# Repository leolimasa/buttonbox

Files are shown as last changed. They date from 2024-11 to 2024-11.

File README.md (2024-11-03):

# buttonbox

A circuit board for Arduino nano with HID buttons for flight simulators.

2x3 rotary encoders in a circuit board.

## Features

* Heading (heading hold)
* Altitude (FLC)
* Vertical speed (VS)
* Speed (IAS hold)
* Altimeter
* COM radio

## Future

The goal is to have a 2x4 rotary encoders board with an extra 8 buttons. 

The amount of switches is limited by the number of pins on the Arduino nano. An alternative to increase that without using a multiplexer is to wire the switches in a matrix.

Each rotary takes 3 buttons. With 8 rotaries, that's 24 buttons.

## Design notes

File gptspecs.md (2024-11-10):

Below are specifications for a program that reads from an arduino serial device and prints the messages to the console. Write the program in Rust, and ensure that each message type has its own separate struct with the appropriate fields, there is a function to parse the raw bytes into the appropriate struct, and a function to print the struct to the console.

Specification:

# Serial protocol

* Each message is a collection of parameters
* A message starts with the STX (start of text) byte
* The message ends with the ETX (end of text) byte
* Parameters are delimited by the US (unit separator) byte

## Message types

Messages are identified by the first parameter. The first parameter is always a single byte that identifies the message type. 

The following message types are supported:

### Rotary change

Message type: `R`

Parameters:

* index, 4 byte int: The index of the rotary encoder that changed
* direction, 1 byte int: The direction of the change. 1 for clockwise, 0 for counter-clockwise

### Rotary click

Message type: `C`

Parameters:

* index, 4 byte int: The index of the rotary encoder that was clicked

# Device detection

Detect any boards that are connected via USB and support the serial protocol and have arduino as their name.
This process should work both in linux, macos, and windows. 

# Main loop

* Identify the serial device to read from, based on the algorithm above
  * If there is more than one device, the user should be prompted to select one 
* Read messages from the serial device, based on the serial protocol and message specification above
* Print the messages to the console

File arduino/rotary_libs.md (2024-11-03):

https://github.com/mathertel/RotaryEncoder
https://github.com/PaulStoffregen/Encoder

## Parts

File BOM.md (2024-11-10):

6 PEC12R-4017F-S0024 https://www.digikey.com/en/products/detail/bourns-inc/PEC12R-4017F-S0024/4699268
1 ARDUINO MICRO
4 M2 SCREWS

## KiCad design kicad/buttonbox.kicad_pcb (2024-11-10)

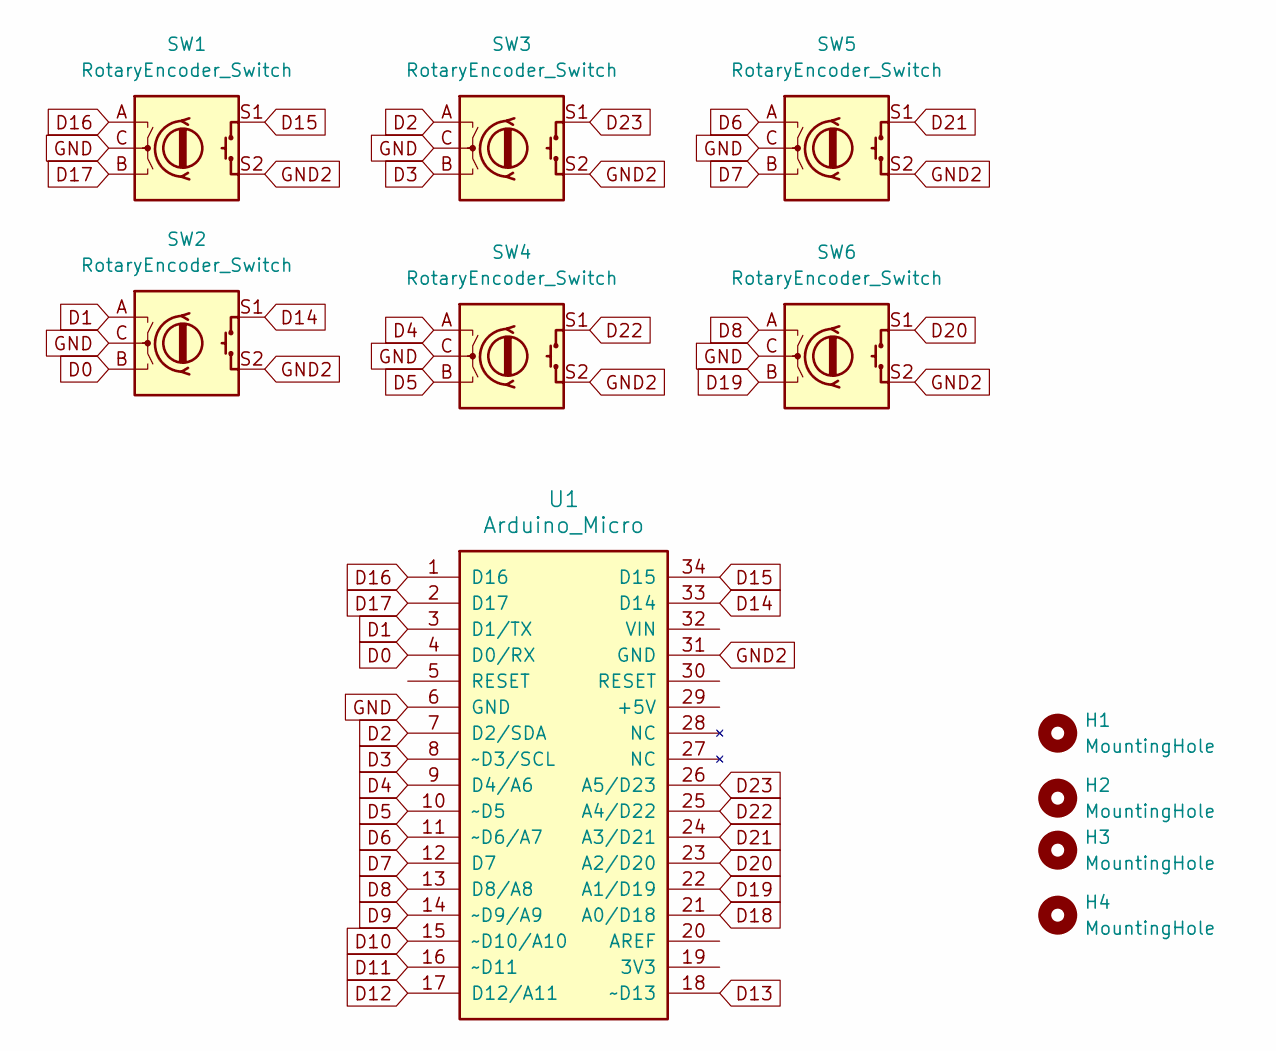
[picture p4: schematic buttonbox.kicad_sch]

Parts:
H1, H2, H3, H4: MountingHole; MountingHole_2.2mm_M2
SW1, SW2, SW3, SW4, SW5, SW6: RotaryEncoder_Switch; RotaryEncoder_Bourns_Vertical_PEC12R-3x17F-Sxxxx
U1: Arduino_Micro

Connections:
D0: SW2.B, U1.4 (D0/RX); also elsewhere on the board
D1: SW2.A, U1.3 (D1/TX); also elsewhere on the board
D2: SW3.A, U1.7 (D2/SDA); also elsewhere on the board
D3: SW3.B, U1.8 (~D3/SCL); also elsewhere on the board
D4: SW4.A, U1.9 (D4/A6); also elsewhere on the board
D5: SW4.B, U1.10 (~D5); also elsewhere on the board
D6: SW5.A, U1.11 (~D6/A7); also elsewhere on the board
D7: SW5.B, U1.12 (D7); also elsewhere on the board
D8: SW6.A, U1.13 (D8/A8); also elsewhere on the board
D14: SW2.S1, U1.33 (D14); also elsewhere on the board
D15: SW1.S1, U1.34 (D15); also elsewhere on the board
D16: SW1.A, U1.1 (D16); also elsewhere on the board
D17: SW1.B, U1.2 (D17); also elsewhere on the board
D19: SW6.B, U1.22 (A1/D19); also elsewhere on the board
D20: SW6.S1, U1.23 (A2/D20); also elsewhere on the board
D21: SW5.S1, U1.24 (A3/D21); also elsewhere on the board
D22: SW4.S1, U1.25 (A4/D22); also elsewhere on the board
D23: SW3.S1, U1.26 (A5/D23); also elsewhere on the board
GND: SW1.C, SW2.C, SW3.C, SW4.C, SW5.C, SW6.C, U1.6 (GND); also elsewhere on the board
GND2: SW1.S2, SW2.S2, SW3.S2, SW4.S2, SW5.S2, SW6.S2, U1.31 (GND); also elsewhere on the board

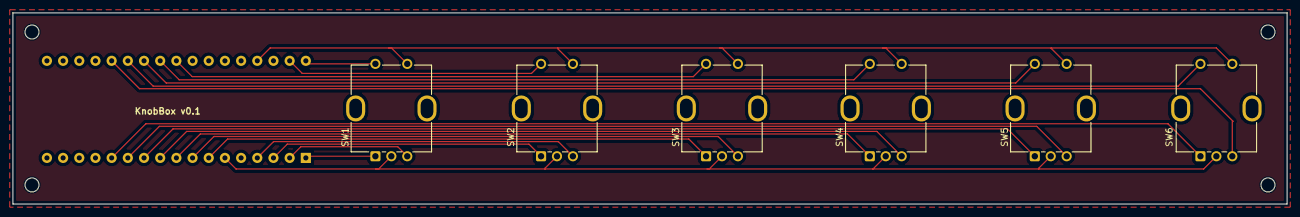
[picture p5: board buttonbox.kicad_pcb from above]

Board: 2 copper layers, 200.0 x 30.0 mm, 11 parts (1 on the bottom side), 20 nets.

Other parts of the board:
Arduino: Arduino_Micro

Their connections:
D0: Arduino.4 (D0/RX); also elsewhere on the board
D1: Arduino.3 (D1/TX); also elsewhere on the board
D2: Arduino.7 (D2/SDA); also elsewhere on the board
D3: Arduino.8 (~D3/SCL); also elsewhere on the board
D4: Arduino.9 (D4/A6); also elsewhere on the board
D5: Arduino.10 (~D5); also elsewhere on the board
D6: Arduino.11 (~D6/A7); also elsewhere on the board
D7: Arduino.12 (D7); also elsewhere on the board
D8: Arduino.13 (D8/A8); also elsewhere on the board
D14: Arduino.33 (D14); also elsewhere on the board
D15: Arduino.34 (D15); also elsewhere on the board
D16: Arduino.1 (D16); also elsewhere on the board
D17: Arduino.2 (D17); also elsewhere on the board
D19: Arduino.22 (A1/D19); also elsewhere on the board
D20: Arduino.23 (A2/D20); also elsewhere on the board
D21: Arduino.24 (A3/D21); also elsewhere on the board
D22: Arduino.25 (A4/D22); also elsewhere on the board
D23: Arduino.26 (A5/D23); also elsewhere on the board
GND: Arduino.6 (GND); also elsewhere on the board
GND2: Arduino.31 (GND); also elsewhere on the board

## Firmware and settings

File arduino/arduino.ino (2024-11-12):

#define DEBUG
#define JOYSTICK_BUTTON_HOLD_MS 50
// #define DEBUG true
#define ENCODER_DO_NOT_USE_INTERRUPTS
#include <Encoder.h>
#include "pb_common.h"
#include "pb.h"
#include "pb_encode.h"
#include "protocol.pb.h"

enum KnobDirection {
  CLOCKWISE,
  COUNTERCLOCKWISE,
  NO_DIRECTION
};

enum KnobButtonEvent {
  BUTTON_PRESSED,
  BUTTON_RELEASED,
  NO_BUTTON_EVENT
};

struct Knob {
  Encoder encoder;
  int pinSwitch;
  long oldPosition;
  int position;
  KnobDirection direction;
  KnobDirection lastDirection;
  unsigned long lastDirectionChangeTime;
  bool isButtonPressed;
  bool lastButtonState;
  bool buttonChanged;
  unsigned long lastButtonChangeTime;

  Knob(uint8_t pinA, uint8_t pinB, int pinSwitch) 
    : encoder(pinA, pinB)
    , pinSwitch(pinSwitch)
    , oldPosition(-999)
    , position(0)
    , lastDirection(NO_DIRECTION)
    , direction(NO_DIRECTION)
    , isButtonPressed(false)
    {}
};

KnobDirection getKnobDirection(struct Knob *knob) {
  if (knob->position > knob->oldPosition) {
    return CLOCKWISE;
  } else if (knob->position < knob->oldPosition) {
    return COUNTERCLOCKWISE;
  }
  return NO_DIRECTION;
}

KnobDirection getKnobStepDirection(struct Knob *knob) {
  if (knob->direction != NO_DIRECTION && knob->position % 4 == 0) {
    return knob->direction;
  }
  return NO_DIRECTION;
}

KnobButtonEvent getKnobButtonEvent(struct Knob *knob) {
  if (knob->isButtonPressed && knob->buttonChanged) {
    return BUTTON_PRESSED;
  } else if (!knob->isButtonPressed && knob->buttonChanged) {
    return BUTTON_RELEASED;
  }
  return NO_BUTTON_EVENT;
}

void setupKnob(struct Knob *knob) {
  pinMode(knob->pinSwitch, INPUT_PULLUP);
}

void updateKnob(struct Knob *knob) {
  unsigned long currentTime = millis();

  knob->position = knob->encoder.read();
  knob->direction = getKnobDirection(knob);

  // If the direction changed too fast, ignore the change
  if (knob->direction != knob->lastDirection) {
    if (currentTime - knob->lastDirectionChangeTime < 70) {
      knob->direction = NO_DIRECTION;
    }
  }

  // Update last direction, but only if there was movement
  if (knob->direction != NO_DIRECTION) {
    knob->lastDirection = knob->direction;
    knob->lastDirectionChangeTime = millis();
  }

  // Update button state, but only if the debounce timer has elapsed
  bool isButtonPressed = digitalRead(knob->pinSwitch) == LOW;
  if (currentTime - knob->lastButtonChangeTime > 50) {
    knob->isButtonPressed = isButtonPressed;
    knob->lastButtonChangeTime = currentTime;
  }

  // Detect whether the button state has changed
  if (knob->isButtonPressed != knob->lastButtonState) {
    knob->buttonChanged = true;
  } else {
    knob->buttonChanged = false;
  }

  knob->lastButtonState = knob->isButtonPressed;
  knob->oldPosition = knob->position;
}

void sendSerialMessage(uint8_t *message, uint8_t len) {
  // Write the 4 byte magic number to identify the start of a message
  Serial.write(0x3d);
  Serial.write(0x01);
  Serial.write(0x6f);
  Serial.write(0x31);

  // Write the message length
  Serial.write(len);

  // Write the message
  for (int i = 0; i < len; i++) {
    Serial.write(message[i]);
  }
}

void sendMessage(protocol_Message *message) {
  uint8_t buffer[256];
  size_t messageLength;
  bool status;

  // Create a stream that will write to our buffer.
  pb_ostream_t stream = pb_ostream_from_buffer(buffer, sizeof(buffer));

  // Encode message
  status = pb_encode(&stream, protocol_Message_fields, message);
  messageLength = stream.bytes_written;

  if (!status) {
    #ifdef DEBUG
    Serial.println("Encoding failed");
    #endif
    return;
  }

  sendSerialMessage(buffer, messageLength);
}

void sendRotaryChange(int32_t index, protocol_Direction direction) {
  protocol_RotaryChange rotaryChange = protocol_RotaryChange_init_default;
  rotaryChange.has_index = true;
  rotaryChange.index = index;
  rotaryChange.has_direction = true;
  rotaryChange.direction = direction;

  protocol_Message message = protocol_Message_init_default;
  message.which_payload = protocol_Message_rotary_change_tag;
  message.payload.rotary_change = rotaryChange;

  sendMessage(&message);
}

void sendButtonChange(int32_t index, bool pressed) {
  protocol_ButtonChange buttonChange = protocol_ButtonChange_init_default;
  buttonChange.has_index = true;
  buttonChange.index = index;
  buttonChange.has_pressed = true;
  buttonChange.pressed = pressed;

  protocol_Message message = protocol_Message_init_default;
  message.which_payload = protocol_Message_button_change_tag;
  message.payload.button_change = buttonChange;

  sendMessage(&message);
}

void sendMessages(int index, struct Knob *knob) {
  KnobDirection direction = getKnobStepDirection(knob);

  // clockwise press
  if (direction == CLOCKWISE) {
    sendRotaryChange(index, protocol_Direction_CLOCKWISE);
  }

  // counterclockwise press
  if (direction == COUNTERCLOCKWISE) {
    sendRotaryChange(index, protocol_Direction_COUNTERCLOCKWISE);
  }

  // button press
  if (getKnobButtonEvent(knob) == BUTTON_PRESSED) {
    sendButtonChange(index, true);
  }

  // button release
  if (getKnobButtonEvent(knob) == BUTTON_RELEASED) {
    sendButtonChange(index, false);
  }
}


// void updateJoystickButtons(struct Knob *knob) {
//   unsigned long currentTime = millis();
//   KnobDirection direction = getKnobStepDirection(knob);
//
//   // clockwise press
//   if (direction == CLOCKWISE) {
//     knob->lastCwJstkBtnTime = currentTime;
//     #ifdef DEBUG
//     Serial.print("clockwise ");
//     #endif
//     if (!knob->jstkCwPressed) {
//       knob->jstkCwPressed = true;
//       Joystick.setButton(knob->jstkCwBtn, true);
//       #ifdef DEBUG
//       Serial.print("press");
//       #endif
//     }
//
//     #ifdef DEBUG
//     Serial.println();
//     #endif
//   }
//
//   // clockwise release
//   if (currentTime - knob->lastCwJstkBtnTime > JOYSTICK_BUTTON_HOLD_MS && direction != CLOCKWISE && knob->jstkCwPressed) {
//     Joystick.setButton(knob->jstkCwBtn, false);
//     knob->jstkCwPressed = false;
//     #ifdef DEBUG
//     Serial.println("clockwise release");
//     #endif
//   }
//
//   // counterclockwise press
//   if (direction == COUNTERCLOCKWISE) {
//     knob->lastCcwJstkBtnTime = currentTime;
//     #ifdef DEBUG
//     Serial.print("counter-clockwise ");
//     #endif
//     if (!knob->jstkCcwPressed) {
//       knob->jstkCcwPressed = true;
//       Joystick.setButton(knob->jstkCcwBtn, true);
//       #ifdef DEBUG
//       Serial.print("press");
//       #endif
//     }
//
//     #ifdef DEBUG
//     Serial.println();
//     #endif
//   }
//
//   // counterclockwise release
//   if (currentTime - knob->lastCcwJstkBtnTime > JOYSTICK_BUTTON_HOLD_MS && direction != COUNTERCLOCKWISE && knob->jstkCcwPressed) {
//     Joystick.setButton(knob->jstkCcwBtn, false);
//     knob->jstkCcwPressed = false;
//     #ifdef DEBUG
//     Serial.println("counter-clockwise release");
//     #endif
//   }
//
//   // button press
//   if (getKnobButtonEvent(knob) == BUTTON_PRESSED) {
//     Joystick.setButton(knob->jstkSwBtn, true);
//     #ifdef DEBUG
//     Serial.println("button pressed");
//     #endif
//   } 
//
//   // button release
//   if (getKnobButtonEvent(knob) == BUTTON_RELEASED) {
//     Joystick.setButton(knob->jstkSwBtn, false);
//     #ifdef DEBUG
//     Serial.println("button released");
//     #endif
//   }
// }


constexpr int knobsLen = 1;
Knob knobs[knobsLen] = {
  Knob(11, 9, 18)
};

void setup() {
  Serial.begin(115200);

  //Joystick.begin();

  for (int i = 0; i < knobsLen; i++) {
    setupKnob(&knobs[i]);
  }
}

void loop() {
  for (int i = 0; i < knobsLen; i++) {
    Knob *knob = &knobs[i];
    updateKnob(knob);
    sendMessages(i, knob);
  }
}

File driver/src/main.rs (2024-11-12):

use std::collections::VecDeque;

mod serial;

fn main() {
    println!("Connecting");
    let ports = serial::detect().unwrap();
    println!("Detected serial device {:?}", ports[0]);
    let mut port = serial::connect(&ports[0]).unwrap();
    println!("Connected to serial device {:?}", port);

    let mut last_4_bytes: VecDeque<u8> = VecDeque::with_capacity(4);

    loop {
        let read_result = serial::read_byte(&mut port);
        let Ok(byte) = read_result else {
            continue;
        };

        // Print byte in hex
        // println!("{:02X}", byte);

        // Add the byte to the last_4_bytes queue.
        last_4_bytes.push_back(byte);
        if last_4_bytes.len() > 4 {
            last_4_bytes.pop_front();
        }

        // If the last 4 bytes match the magic sequence, then we have a message.
        if last_4_bytes.len() == 4 
            && last_4_bytes[0] == 0x3d 
            && last_4_bytes[1] == 0x01 
            && last_4_bytes[2] == 0x6f 
            && last_4_bytes[3] == 0x31 {

            // Read the next byte to get the message length.
            let message_length = match serial::read_byte(&mut port) {
                Ok(byte) => byte,
                Err(e) => {
                    // clear last last_4_bytes and continue
                    println!("Error reading message length: {:?}", e);
                    last_4_bytes.clear();
                    continue;
                }
            };
           
            // Read the message
            let message = match serial::read_message(&mut port, message_length) {
                Ok(message) => message,
                Err(e) => {
                    // clear last last_4_bytes and continue
                    println!("Error reading message: {:?}", e);
                    last_4_bytes.clear();
                    continue;
                }
            };
            println!("{:?}", message);
        }



        // Prints params content in hex for each vec item

        // let msg = serial::parse(params).unwrap();
        //
        // match msg {
        //     serial::Message::RotaryChange { index, value } => {
        //         println!("RotaryChange: index: {}, value: {}", index, value);
        //     },
        //     serial::Message::ButtonPress { index } => {
        //         println!("ButtonPress: index: {}", index);
        //     },
        //     serial::Message::ButtonRelease { index } => {
        //         println!("ButtonRelease: index: {}", index);
        //     },
        //     serial::Message::Debug { message } => {
        //         println!("Debug: message: {}", message);
        //     }
        // }
    }
}

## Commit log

2024-11-03 started on arduino code
    [buttonbox.kicad_pcb, buttonbox.kicad_sch]
2024-11-04 button works
2024-11-04 rotary joystick button hold
2024-11-10 kicad board and preparing for protobuf
    [buttonbox-B_Cu.gbr, buttonbox-B_Mask.gbr, buttonbox-B_Paste.gbr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]
2024-11-10 removed old kicad files
    [buttonbox.kicad_pcb, buttonbox.kicad_sch]
2024-11-12 renamed main folders
    [buttonbox-B_Cu.gbr, buttonbox-B_Mask.gbr, buttonbox-B_Paste.gbr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]
2024-11-12 serial driver works with protobuf
